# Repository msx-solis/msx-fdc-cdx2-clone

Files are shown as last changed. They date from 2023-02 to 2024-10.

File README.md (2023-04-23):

# msx-fdc-cdx2-clone
MSX compatible I/O Port Based Floppy Disk Controller interface.

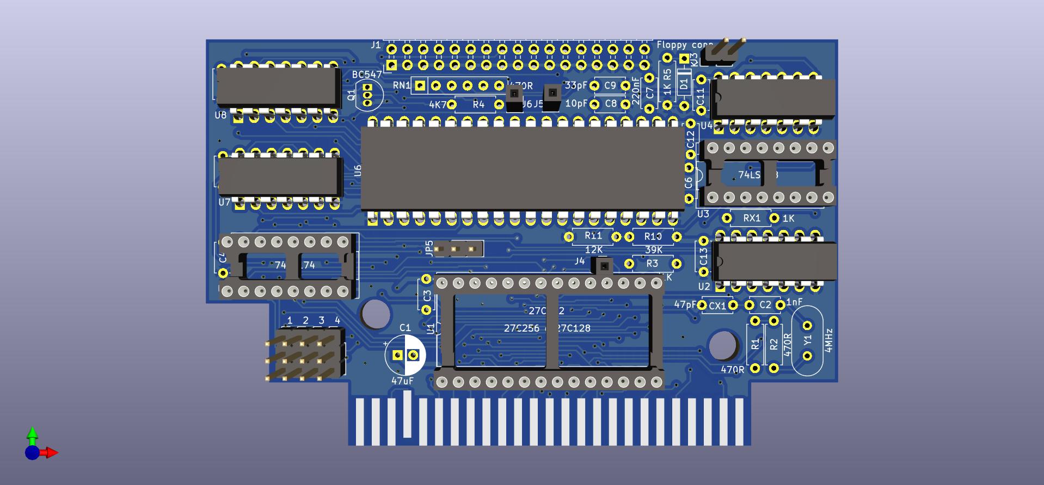
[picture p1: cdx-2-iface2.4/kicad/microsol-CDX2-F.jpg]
card


Please, continue reading at the following link for building instructions:

https://github.com/msx-solis/msx-fdc-cdx2-clone/blob/main/cdx-2-iface2.4/doc/README.md

Special thanks to Paulo Maluf, XaviRompe, Andortizg and konkotgit.

Similar project and additional info at:

https://github.com/konkotgit/fdd-cdx2

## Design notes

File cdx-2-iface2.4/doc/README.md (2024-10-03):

# Step by step debugging instructions
## Port Based Floppy Disk Drive controller for MSX computer

Recreated Microsol Tecnologia CDX-2 FDD interface with busdir signal upgrade.

### ROMs tested with this interface:

* CDX-2 (Microsol Tecnologia)
* Angeisa (Angeisa Eletronica LTDA)
* FAST!DiskROM

### ROMs that should work with this interface:

* DDX 1.0 (Digital Design)
* DMX 1.2 (Conector Informatica LTDA.)
* LIFTROM (Liftrom Informatica)
* MANUT (AMT Mamute)
* TPX 1.02 (TPX - Perifericos)

### ROM vs free BASIC memory

| ROM | Free BASIC Memory |
| --- |:---:|
| Angeisa (Angeisa Eletronica LTDA)  | 23430  |
| CDX-2 (Microsol Tecnologia)  | 23430  |
| DDX 1.0 (Digital Design)  | 20304  |
| DMX 1.2 (Conector Informatica LTDA.) | 20304  |
| LIFTROM (Liftrom Informatica)  | 20304  |
| MANUT (AMT Mamute)  | 23430  |
| TPX 1.02 (TPX - Perifericos)  | 23430  |
| FAST!DiskROM  | 25471  |

Solder in all components and sockets, using round pin sockets you should have a low profile design.
The Jumpers JP1 to JP4 should link 1-2 for standard MSX connection and 2-3 for to use a standard PC ribbon cable, but drive b: may not work in this case (test not done yet). JP5 selects the ROM software between two options.

Then follow the next testing steps.

First insert the 74LS00 and verify you have 4Mhz measuring here (you need a frequency-meter or an oscilloscope):
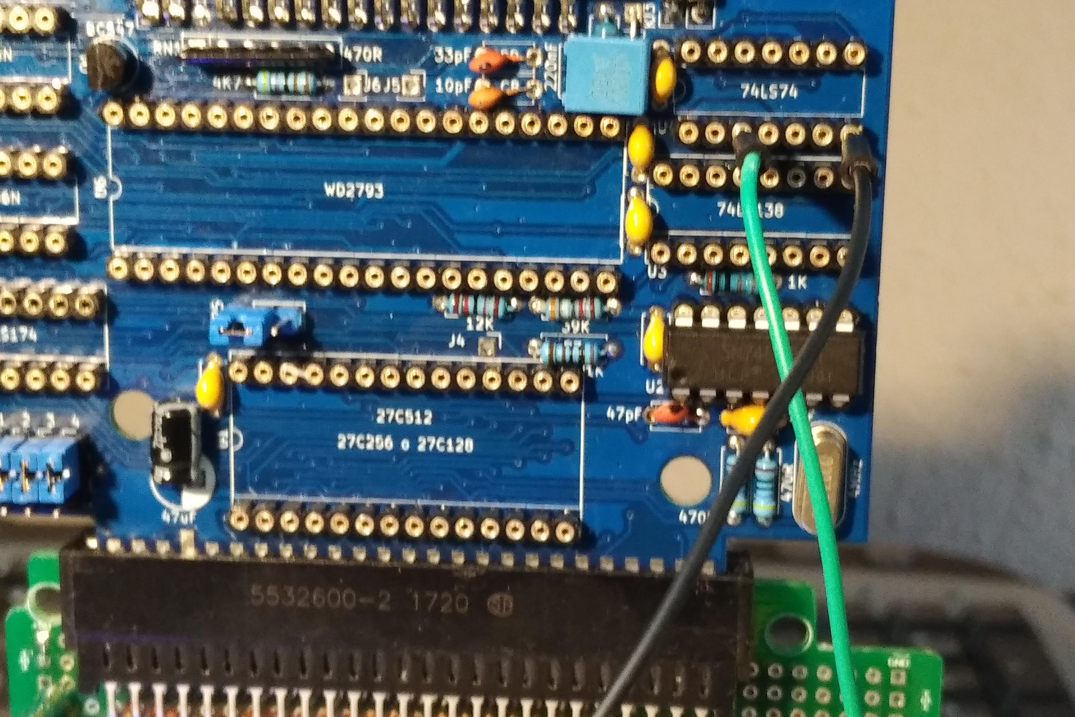
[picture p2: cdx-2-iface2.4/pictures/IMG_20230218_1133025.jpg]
4Mhz

Same way you can insert the 74LS74 IC and test you have 1Mhz here:
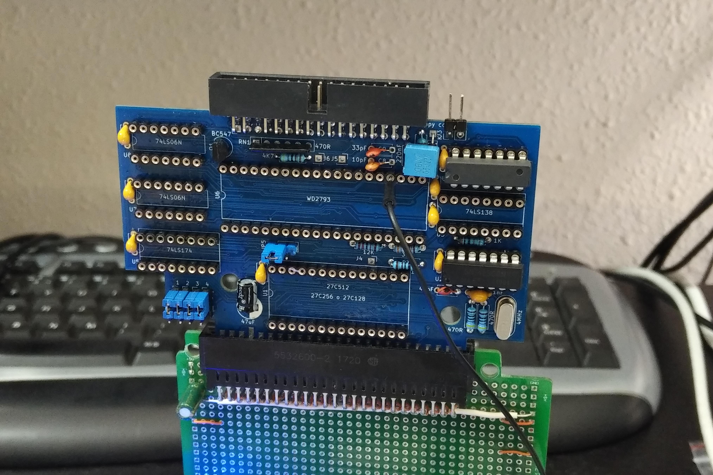
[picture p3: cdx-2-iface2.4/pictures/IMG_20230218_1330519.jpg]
1Mhz

Then test the reading select circuit is working properly doing the test shown in the following picture (and testing the result with a logic probe or a voltmeter):
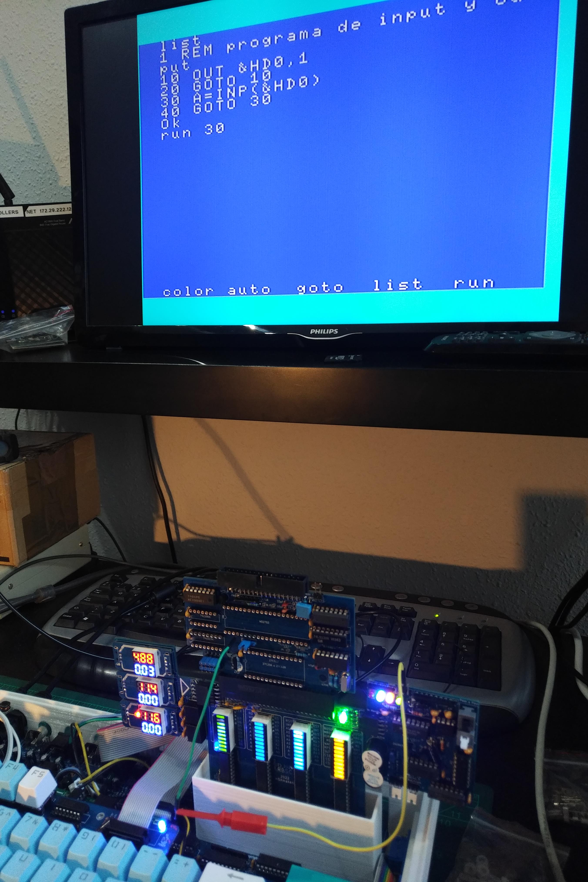
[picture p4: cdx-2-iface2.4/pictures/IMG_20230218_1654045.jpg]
read

You can use the same program (push ctrl-stop and RUN) for test writing port select circuit too (with the probe pin inserted at pin 2).
Click at the below picture to see a video showing it:
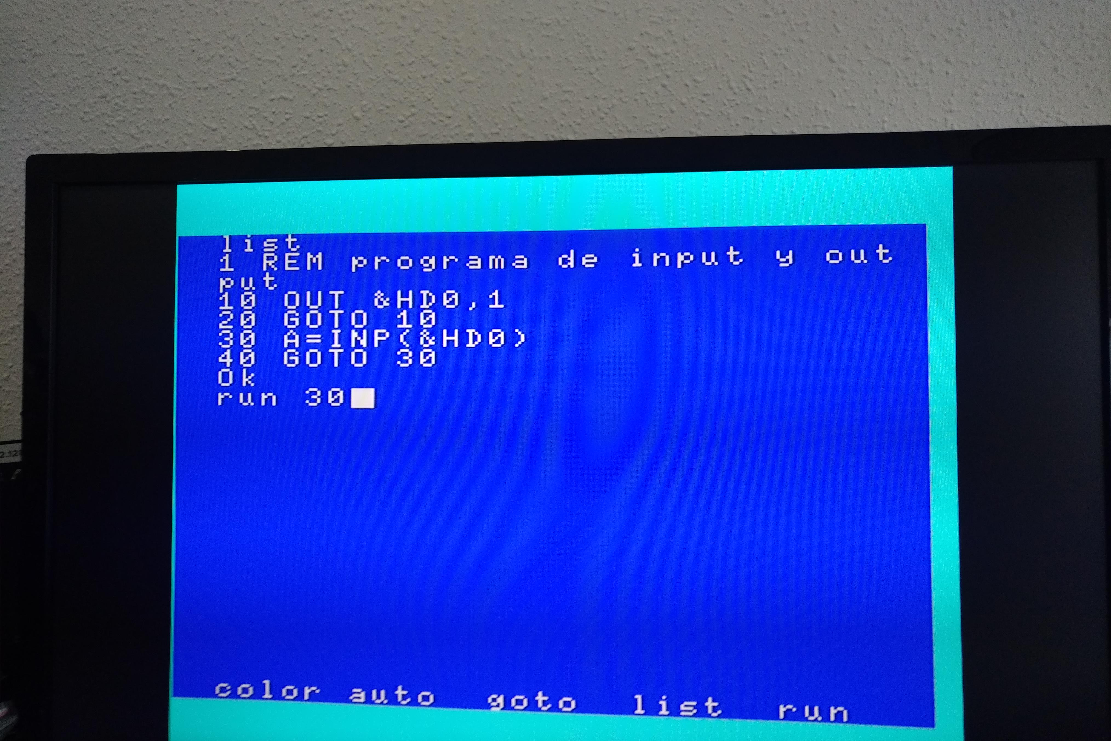
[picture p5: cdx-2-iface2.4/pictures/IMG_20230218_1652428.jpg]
YouTube link (https://youtu.be/hXyXDxHcx18)

After that you can also probe the hex D4 port with the following procedure:
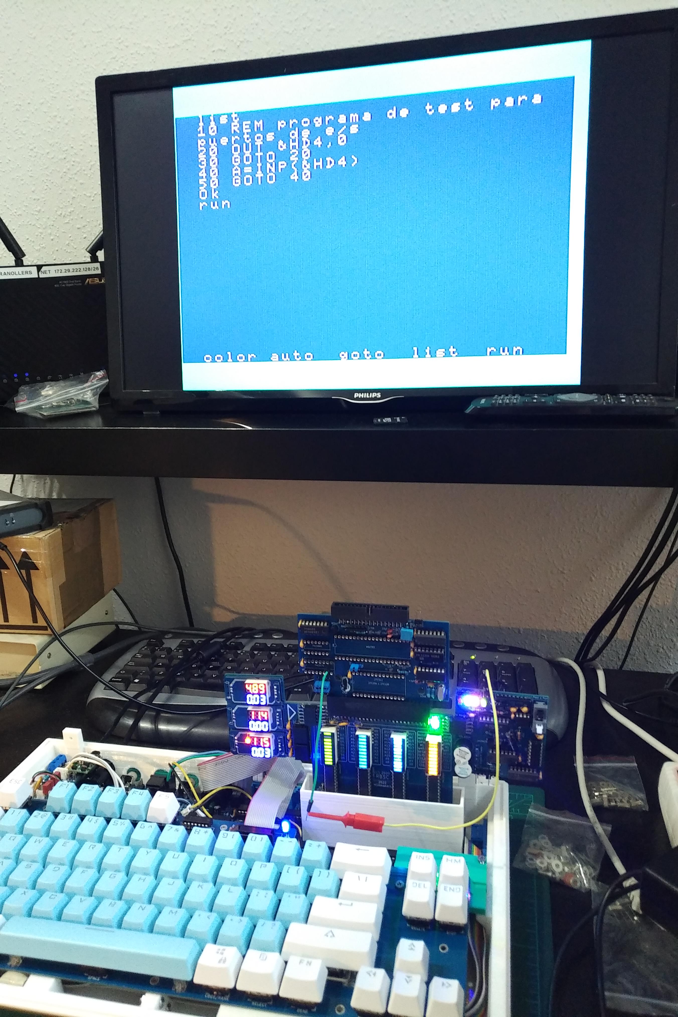
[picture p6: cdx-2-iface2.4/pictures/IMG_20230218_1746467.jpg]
D4

Now you must configure the jumpers JP1 to JP4 for the right drive and the right wire:

* To use an old DS0 MSX drive, build a direct straight ribbon cable and choose 1-2 at four jumpers. Direct straight drive connected will be A: and switching wires 10-12 drive B: DS0 (MSX) can be connected.
* To use a common DS1 PC drive and a ribbon PC twisted cable (with 10 to 16 wires crossed) chose 2-3 at those jumpers (only drive A will work).
* PC drives can also be used with an MSX setup, with a 10 to 12 ribbon twisted wire. For this setup move jumpers JP1-JP4 to 1-2 and connect two PC drives: direct straight will be drive B: and drive connected after switching 10-12 will be drive A:.
* Some drives also lets you choose what DS setup they are by jumpers, then use a direct straight ribbon cable with up to 5 connectors (4 drives) and setup each drive from DS0 to DS3.

Now try the following output commands (to test DS0 ON, DS1 ON, motor ON...) and test on the related pins. to know what should be the affected pin you must follow the schematic...
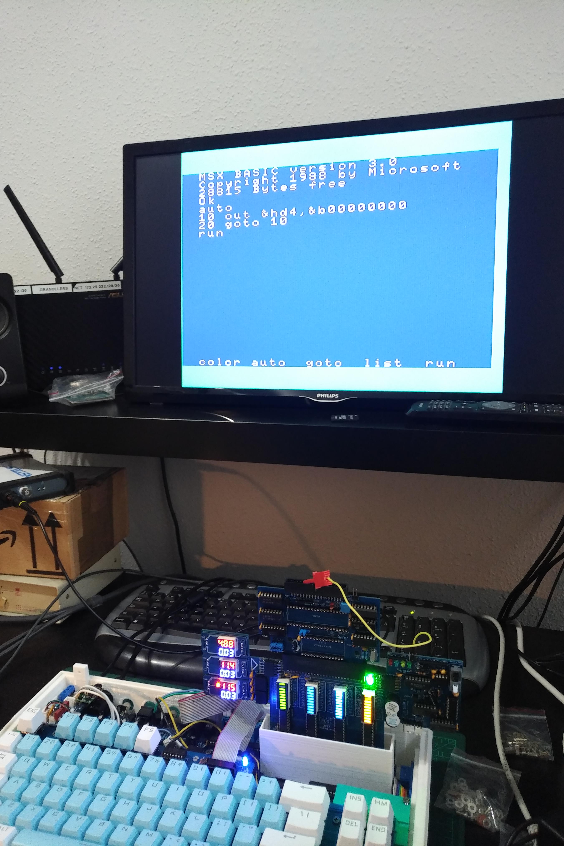
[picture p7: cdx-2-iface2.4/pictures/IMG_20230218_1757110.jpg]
binary1

...or you can connect now the floppy drive and test it. &b00100001 should on the A drive led, there's also bits for motor, etc:
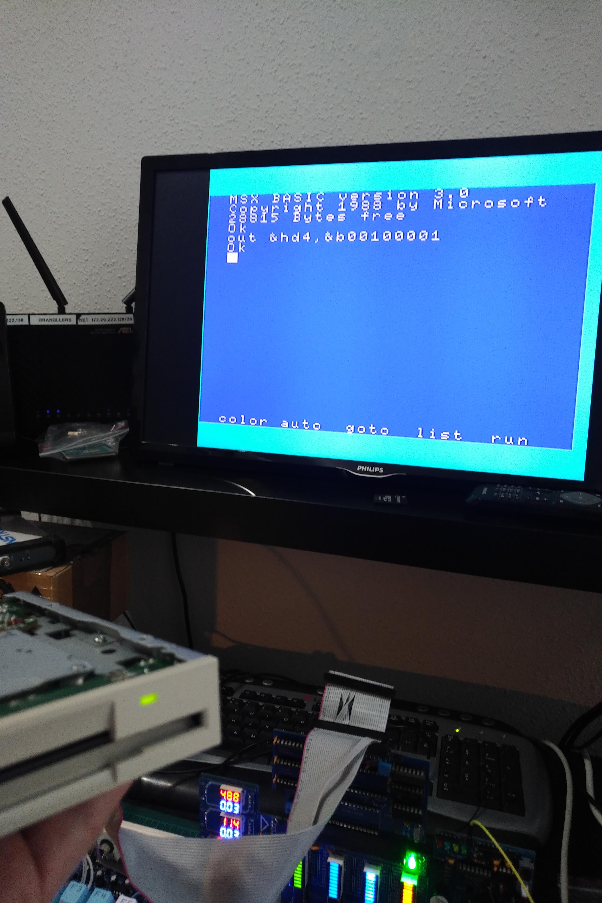
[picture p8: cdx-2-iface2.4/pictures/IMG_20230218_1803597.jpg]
binary2
 
Then, insert all pending IC and configure the JP5 to select your favorite ROM driver and try with a disk drive.
Angesia ROM would be the better software to use during the test process and FAST!DiskROM could be better option to improve the disk performance.

Floppy disk support must be formatted at the right format, MSX system does not support High density disks.
This means 3.5 HD disks must be formated after bloking the HD hole, using 720k/360k format (DSDD 80/40 tracks), and 5.25" disks must be also setup for 360k.
You can use a tool from a PC to dump MSX disks, is called Disk Manager: http://www.lexlechz.at/en/software/DiskMgr.html
Then you can use the disk dumps fount at https://download.file-hunter.com/ and get access to lots of software/games.

There's also lots of information for troubleshooting this interface reading the TMS2793 datasheet.
https://github.com/msx-solis/msx-fdc-cdx2-clone/raw/main/cdx-2-iface2.4/doc/tms2793.pdf

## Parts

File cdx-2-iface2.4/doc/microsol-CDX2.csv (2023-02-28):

Reference | Quantity | Value | Footprint | Datasheet
1 | 1 | DS0-sel | Connector_PinHeader_2.54mm:PinHeader_1x03_P2.54mm_Vertical
2 | 1 | DS1-sel | Connector_PinHeader_2.54mm:PinHeader_1x03_P2.54mm_Vertical
3 | 1 | DS2-sel | Connector_PinHeader_2.54mm:PinHeader_1x03_P2.54mm_Vertical
4 | 1 | MOTOR-sel | Connector_PinHeader_2.54mm:PinHeader_1x03_P2.54mm_Vertical
C1 | 1 | 47uF | Capacitor_THT:CP_Radial_D6.3mm_P2.50mm
C2 | 1 | 1nF | Capacitor_THT:C_Disc_D4.7mm_W2.5mm_P5.00mm
C3 C4 C5 C6 C10 C11 C12 C13 | 8 | 100nF | Capacitor_THT:C_Disc_D4.7mm_W2.5mm_P5.00mm
C7 | 1 | 220nF | Capacitor_THT:C_Disc_D4.7mm_W2.5mm_P5.00mm
C8 | 1 | 10pF | Capacitor_THT:C_Disc_D4.7mm_W2.5mm_P5.00mm
C9 | 1 | 33pF | Capacitor_THT:C_Disc_D4.7mm_W2.5mm_P5.00mm
CX1 | 1 | 47pF | Capacitor_THT:C_Disc_D4.7mm_W2.5mm_P5.00mm
D1 | 1 | 1N4148 | Diode_THT:D_DO-35_SOD27_P7.62mm_Horizontal | https://assets.nexperia.com/documents/data-sheet/1N4148_1N4448.pdf
J1 | 1 | Floppy conn | Connector_PinHeader_2.54mm:PinHeader_2x17_P2.54mm_Horizontal
J2 | 1 | MSX_SLOT_CON | MSXMakers:CARTRIDGE_#_MSX_XL
J3 | 1 | Test | Connector_PinHeader_2.54mm:PinHeader_1x02_P2.54mm_Vertical
J4 | 1 | TestPoint1 | Connector_PinSocket_2.54mm:PinSocket_1x01_P2.54mm_Vertical
J5 | 1 | TestPoint2 | Connector_PinSocket_2.54mm:PinSocket_1x01_P2.54mm_Vertical
J6 | 1 | TestPoint3 | Connector_PinSocket_2.54mm:PinSocket_1x01_P2.54mm_Vertical
JP5 | 1 | ROM_SW | Connector_PinHeader_2.54mm:PinHeader_1x03_P2.54mm_Vertical
Q1 | 1 | BC547 | Package_TO_SOT_THT:TO-92_Inline | https://www.onsemi.com/pub/Collateral/BC550-D.pdf
R1 R2 | 2 | 470R | Resistor_THT:R_Axial_DIN0207_L6.3mm_D2.5mm_P7.62mm_Horizontal
R10 | 1 | 39K | Resistor_THT:R_Axial_DIN0207_L6.3mm_D2.5mm_P7.62mm_Horizontal
R11 | 1 | 12K | Resistor_THT:R_Axial_DIN0207_L6.3mm_D2.5mm_P7.62mm_Horizontal
RX1 R3 R5 | 3 | 1K | Resistor_THT:R_Axial_DIN0207_L6.3mm_D2.5mm_P7.62mm_Horizontal
R4 | 1 | 4K7 | Resistor_THT:R_Axial_DIN0207_L6.3mm_D2.5mm_P7.62mm_Horizontal
RN1 | 1 | 470R | Resistor_THT:R_Array_SIP6 | http://www.vishay.com/docs/31509/csc.pdf
U1 | 1 | 27C256 o 27C128 | MSXmakers:DIP-28c_W15.24mm_Socket_LongPads | http://ww1.microchip.com/downloads/en/DeviceDoc/doc0014.pdf
U2 | 1 | 74LS00 | MSXmakers:DIP-14c_W7.62mm_LongPads | http://www.ti.com/lit/gpn/sn74ls00
U3 | 1 | 74LS138 | MSXmakers:DIP-16c_W7.62mm_Socket_LongPads | http://www.ti.com/lit/gpn/sn74LS138
U4 | 1 | 74LS74 | MSXmakers:DIP-14c_W7.62mm_LongPads | 74xx/74hc_hct74.pdf
U5 | 1 | 74LS174 | MSXmakers:DIP-16c_W7.62mm_Socket_LongPads | http://www.ti.com/lit/gpn/sn74LS174
U6 | 1 | WD2793 | MSXmakers:DIP-40c_W15.24mm_LongPads | http://pdf.datasheetcatalog.com/datasheets2/12/1229802_1.pdf
U7 U8 | 2 | 74LS06N | MSXmakers:DIP-14c_W7.62mm_LongPads | http://www.ti.com/lit/gpn/sn74LS06N
Y1 | 1 | 4MHz | Crystal:Crystal_HC49-U_Vertical

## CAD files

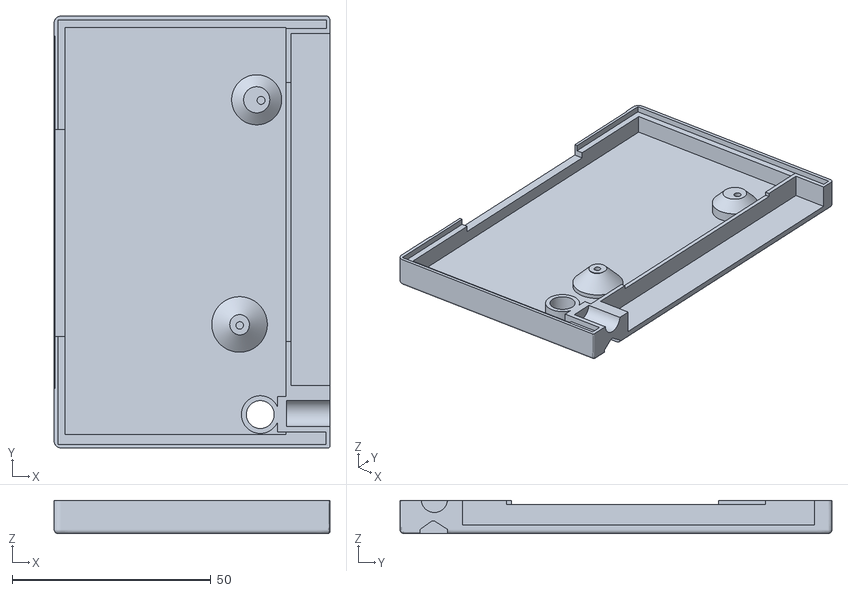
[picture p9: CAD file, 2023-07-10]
cartridge-case/cdx-2-2.4-case_botton.stl
69.3 x 108.6 x 8.30

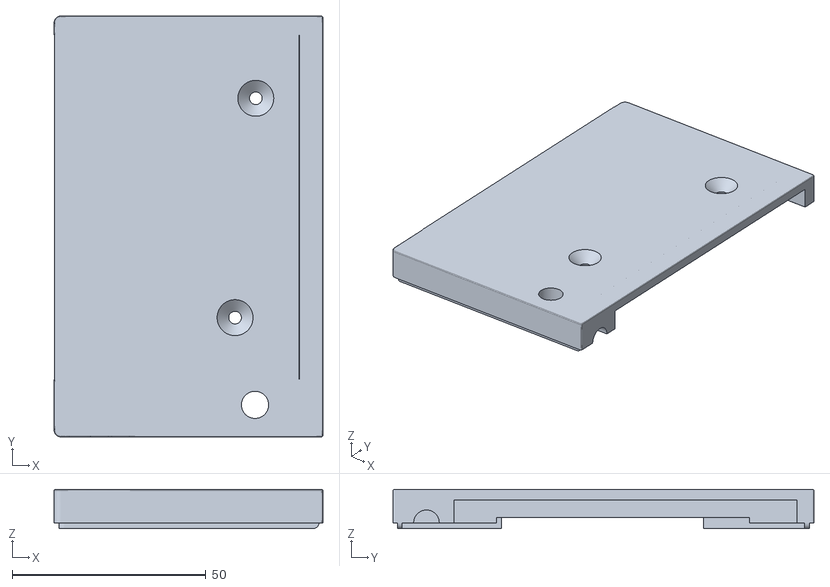
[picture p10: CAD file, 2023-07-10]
cartridge-case/cdx-2-2.4-case_top.stl
69.3 x 108.6 x 10.1

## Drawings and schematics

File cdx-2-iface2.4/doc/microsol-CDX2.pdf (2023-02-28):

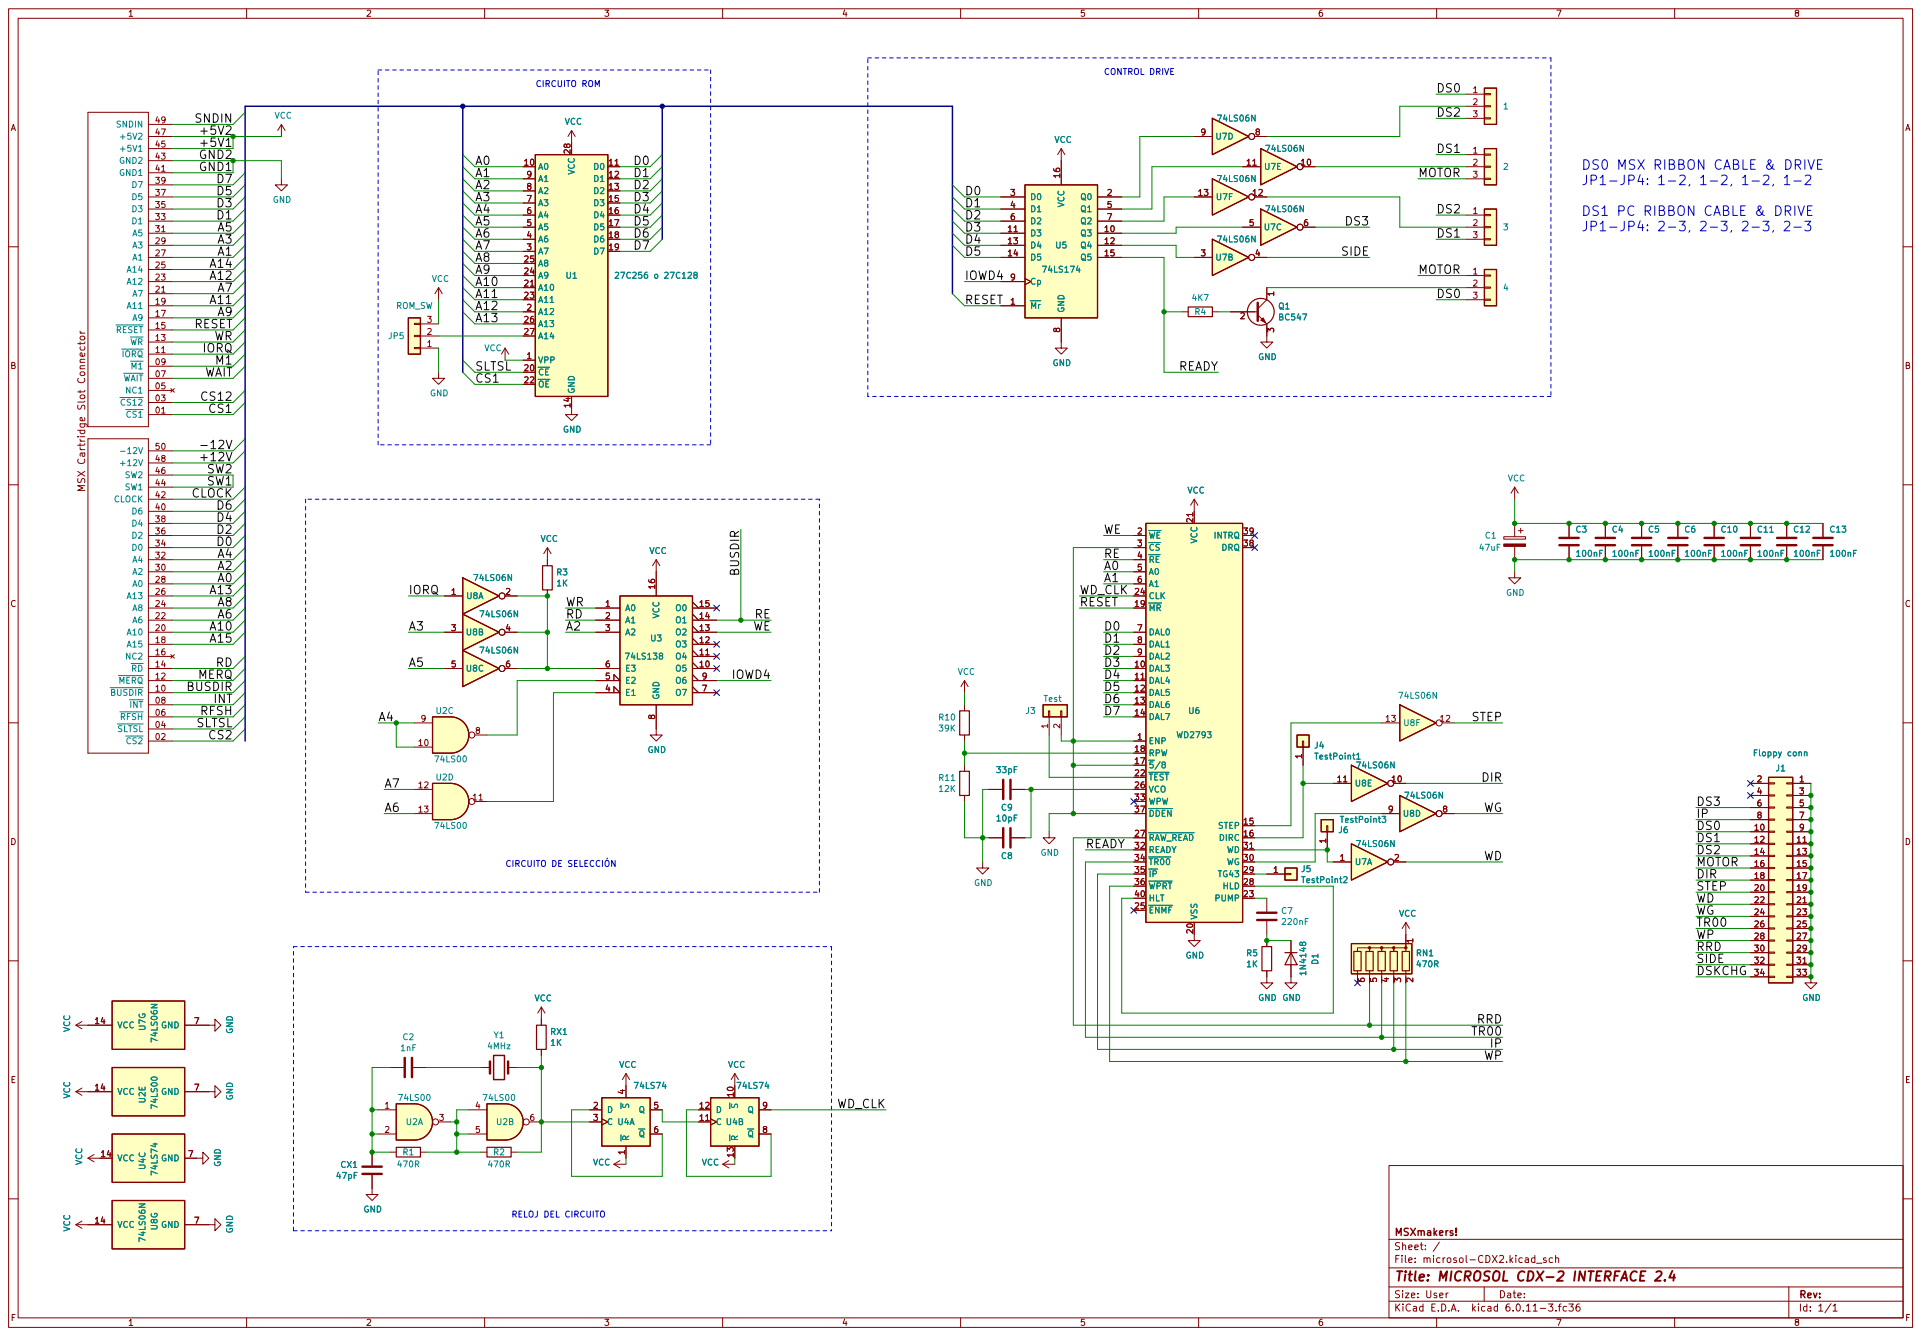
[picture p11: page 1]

CONTROL DRIVE

DS1 PC RIBBON CABLE & DRIVE

RESET

VCC MSX Cartridge Slot Connector

File: microsol-CDX2.kicad_sch Sheet: / MSXmakers!

Id: 1/1 Title: MICROSOL CDX-2 INTERFACE 2.4

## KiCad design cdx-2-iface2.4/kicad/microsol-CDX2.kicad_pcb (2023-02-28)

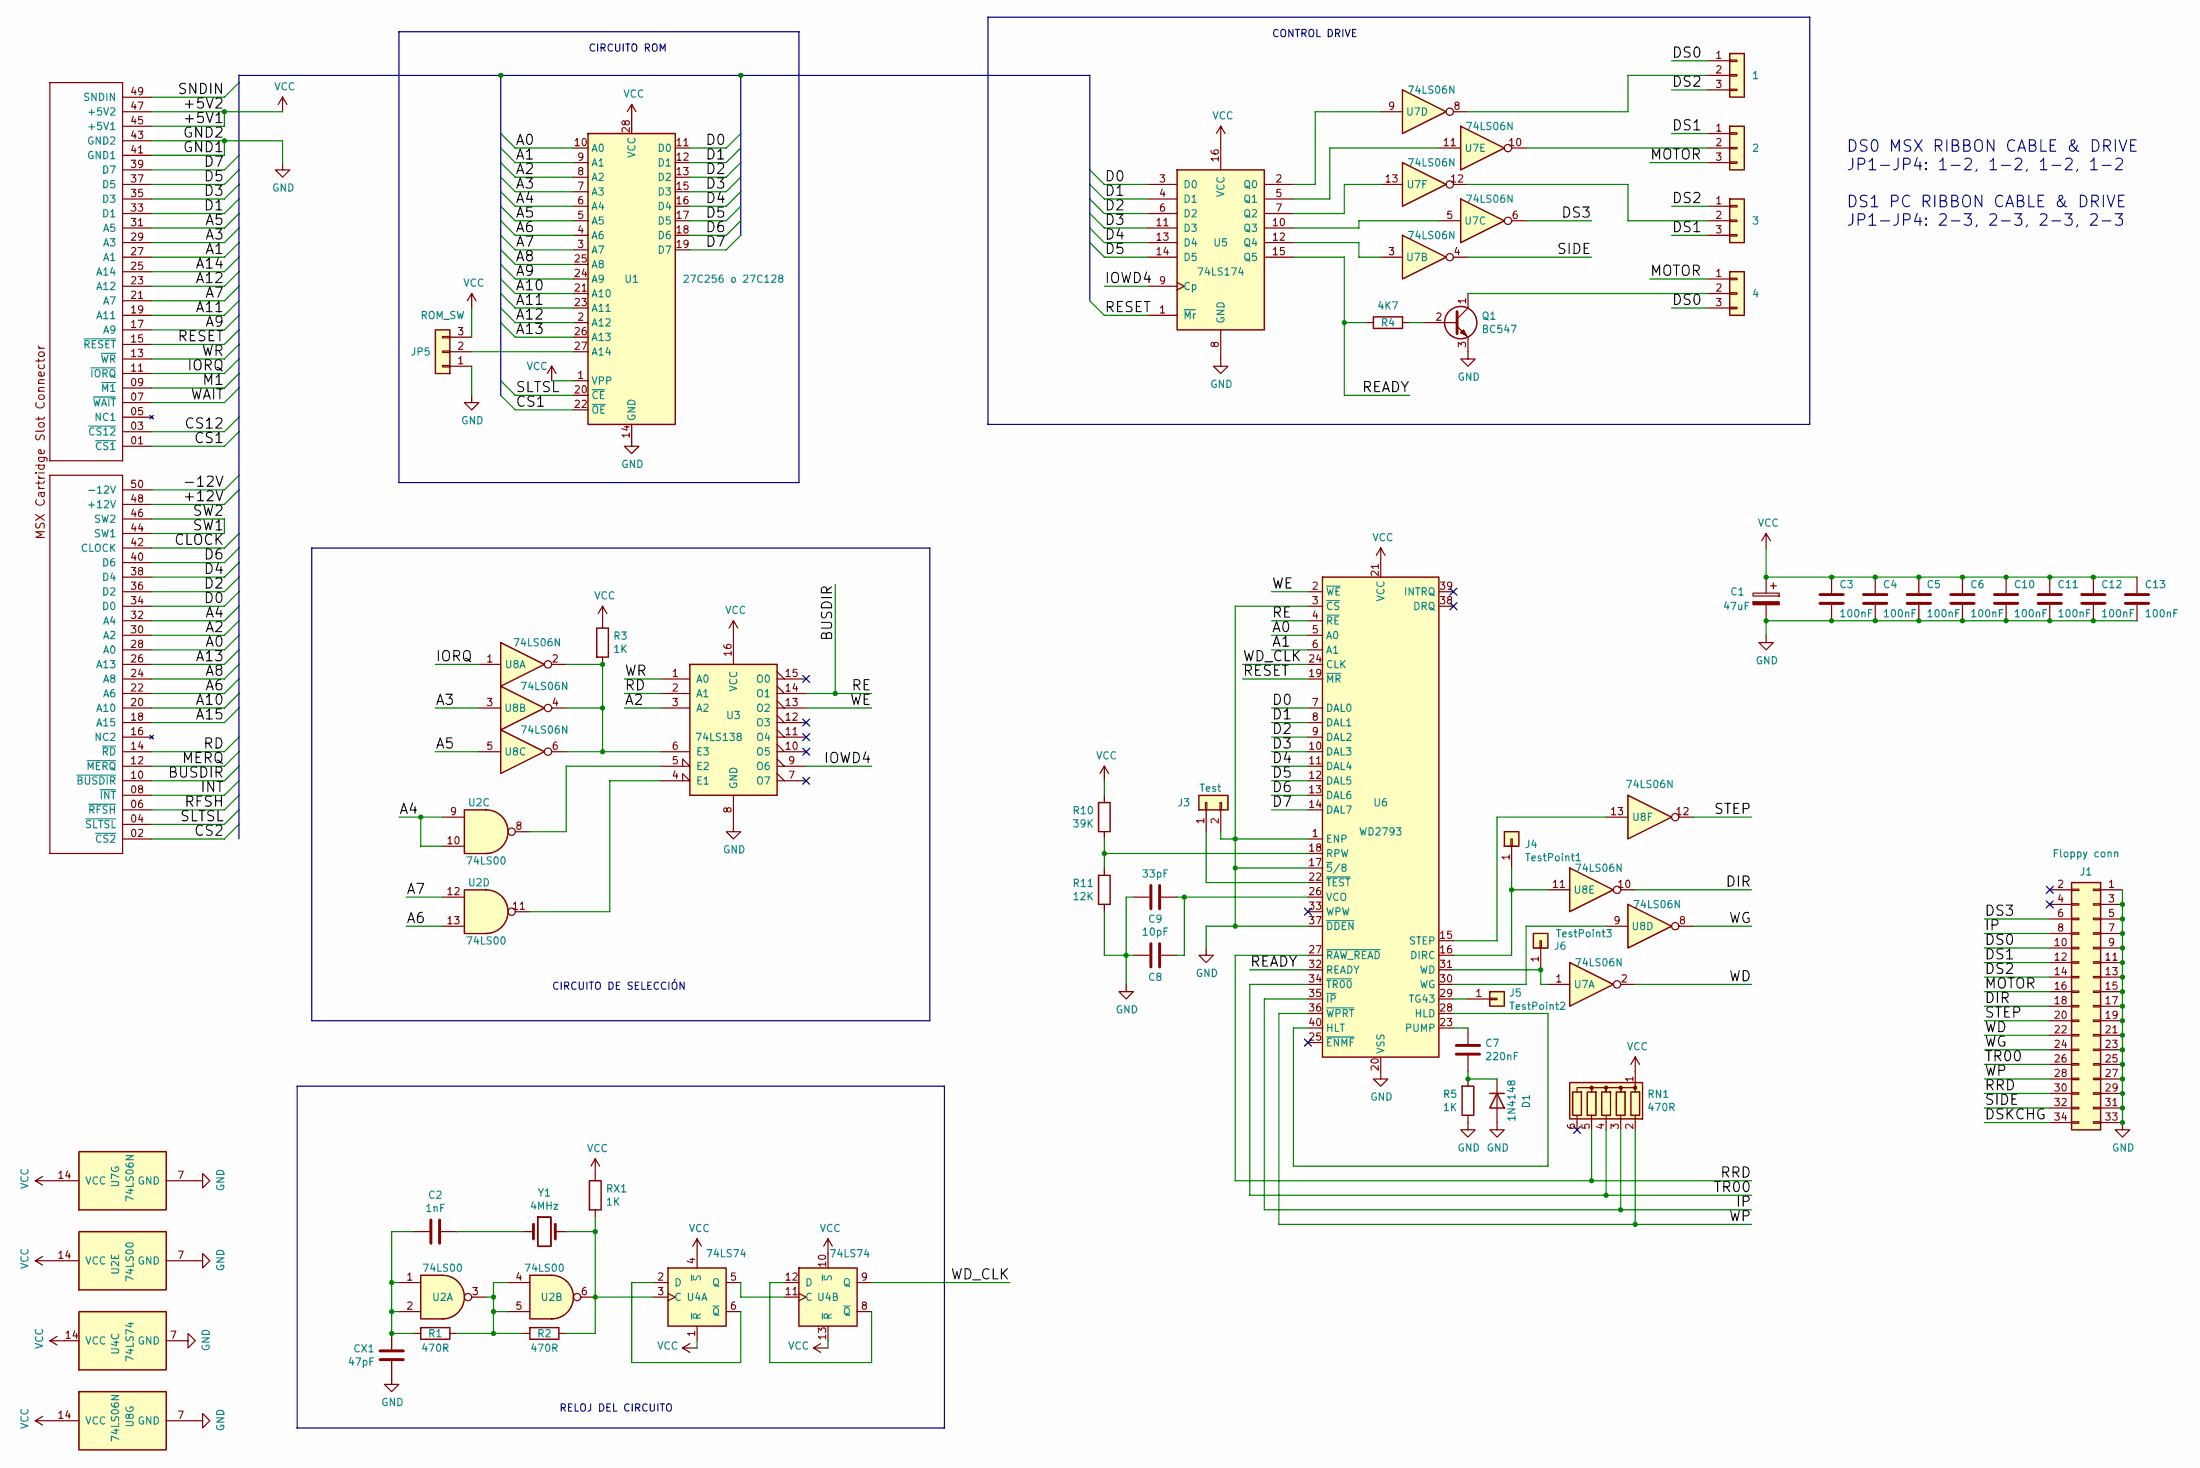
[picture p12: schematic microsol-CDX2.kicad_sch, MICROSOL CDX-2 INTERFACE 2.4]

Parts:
1: DS0-sel; PinHeader_1x03_P2.54mm_Vertical
2: DS1-sel; PinHeader_1x03_P2.54mm_Vertical
3: DS2-sel; PinHeader_1x03_P2.54mm_Vertical
4: MOTOR-sel; PinHeader_1x03_P2.54mm_Vertical
C1: 47uF; CP_Radial_D6.3mm_P2.50mm
C2: 1nF; C_Disc_D4.7mm_W2.5mm_P5.00mm
C3, C4, C5, C6, C10, C11, C12, C13: 100nF; C_Disc_D4.7mm_W2.5mm_P5.00mm
C7: 220nF; C_Disc_D4.7mm_W2.5mm_P5.00mm
C8: 10pF; C_Disc_D4.7mm_W2.5mm_P5.00mm
C9: 33pF; C_Disc_D4.7mm_W2.5mm_P5.00mm
CX1: 47pF; C_Disc_D4.7mm_W2.5mm_P5.00mm
D1: 1N4148; D_DO-35_SOD27_P7.62mm_Horizontal
J1: Floppy conn; PinHeader_2x17_P2.54mm_Horizontal
J2: MSX_SLOT_CON; CARTRIDGE_#_MSX_XL
J3: Test; PinHeader_1x02_P2.54mm_Vertical
J4: TestPoint1; PinSocket_1x01_P2.54mm_Vertical
J5: TestPoint2; PinSocket_1x01_P2.54mm_Vertical
J6: TestPoint3; PinSocket_1x01_P2.54mm_Vertical
JP5: ROM_SW; PinHeader_1x03_P2.54mm_Vertical
Q1: BC547; TO-92_Inline
R1, R2: 470R; R_Axial_DIN0207_L6.3mm_D2.5mm_P7.62mm_Horizontal
R3, R5: 1K; R_Axial_DIN0207_L6.3mm_D2.5mm_P7.62mm_Horizontal
R4: 4K7; R_Axial_DIN0207_L6.3mm_D2.5mm_P7.62mm_Horizontal
R10: 39K; R_Axial_DIN0207_L6.3mm_D2.5mm_P7.62mm_Horizontal
R11: 12K; R_Axial_DIN0207_L6.3mm_D2.5mm_P7.62mm_Horizontal
RN1: 470R; R_Array_SIP6
RX1: 1K; R_Axial_DIN0207_L6.3mm_D2.5mm_P7.62mm_Horizontal
U1: 27C256 o 27C128; DIP-28c_W15.24mm_Socket_LongPads
U2: 74LS00; DIP-14c_W7.62mm_LongPads
U3: 74LS138; DIP-16c_W7.62mm_Socket_LongPads
U4: 74LS74; DIP-14c_W7.62mm_LongPads
U5: 74LS174; DIP-16c_W7.62mm_Socket_LongPads
U6: WD2793; DIP-40c_W15.24mm_LongPads
U7, U8: 74LS06N; DIP-14c_W7.62mm_LongPads
Y1: 4MHz; Crystal_HC49-U_Vertical

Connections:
/+12V: J2.48 (+12V)
/-12V: J2.50 (-12V)
/A0: J2.28 (A0), U1.10 (A0), U6.5 (A0)
/A1: J2.27 (A1), U1.9 (A1), U6.6 (A1)
/A2: J2.30 (A2), U1.8 (A2), U3.3 (A2)
/A3: J2.29 (A3), U1.7 (A3), U8.3
/A4: J2.32 (A4), U1.6 (A4), U2.9, U2.10
/A5: J2.31 (A5), U1.5 (A5), U8.5
/A6: J2.22 (A6), U1.4 (A6), U2.13
/A7: J2.21 (A7), U1.3 (A7), U2.12
/A8: J2.24 (A8), U1.25 (A8)
/A9: J2.17 (A9), U1.24 (A9)
/A10: J2.20 (A10), U1.21 (A10)
/A11: J2.19 (A11), U1.23 (A11)
/A12: J2.23 (A12), U1.2 (A12)
/A13: J2.26 (A13), U1.26 (A13)
/A14: J2.25 (A14)
/A15: J2.18 (A15)
/BUSDIR: J2.10 (~BUSDIR), U3.14 (O1), U6.4 (~RE)
/CLOCK: J2.42 (CLOCK)
/CS1: J2.01 (~CS1), U1.22 (~OE)
/CS2: J2.02 (~CS2)
/CS12: J2.03 (~CS12)
/D0: J2.34 (D0), U1.11 (D0), U5.3 (D0), U6.7 (DAL0)
/D1: J2.33 (D1), U1.12 (D1), U5.4 (D1), U6.8 (DAL1)
/D2: J2.36 (D2), U1.13 (D2), U5.6 (D2), U6.9 (DAL2)
/D3: J2.35 (D3), U1.15 (D3), U5.11 (D3), U6.10 (DAL3)
/D4: J2.38 (D4), U1.16 (D4), U5.13 (D4), U6.11 (DAL4)
/D5: J2.37 (D5), U1.17 (D5), U5.14 (D5), U6.12 (DAL5)
/D6: J2.40 (D6), U1.18 (D6), U6.13 (DAL6)
/D7: J2.39 (D7), U1.19 (D7), U6.14 (DAL7)
/DIR: J1.18, U8.10
/DS0: 1.1, 4.3, J1.10
/DS1: 2.1, 3.3, J1.12
/DS2: 1.3, 3.1, J1.14
/DS3: J1.6, U7.6
/DSKCHG: J1.34
/INT: J2.08 (~INT)
/IORQ: J2.11 (~IORQ), U8.1
/IOWD4: U3.9 (O6), U5.9 (Cp)
/IP: J1.8, RN1.3 (R2), U6.35 (~IP)
/M1: J2.09 (~M1)
/MERQ: J2.12 (~MERQ)
/MOTOR: 2.3, 4.1, J1.16
/RD: J2.14 (~RD), U3.2 (A1)
/READY: R4.1, U5.15 (Q5), U6.32 (READY)
/RESET: J2.15 (~RESET), U5.1 (~Mr), U6.19 (~MR)
/RFSH: J2.06 (~RFSH)
/RRD: J1.30, RN1.5 (R4), U6.27 (~RAW_READ)
/SIDE: J1.32, U7.4
/SLTSL: J2.04 (~SLTSL), U1.20 (~CE)
/SNDIN: J2.49 (SNDIN)
/STEP: J1.20, U8.12
/SW1: J2.44 (SW1), J2.46 (SW2)
/TR00: J1.26, RN1.4 (R3), U6.34 (~TR00)
/WAIT: J2.07 (~WAIT)
/WD: J1.22, U7.2
/WD_CLK: U4.9 (Q), U6.24 (CLK)
/WE: U3.13 (O2), U6.2 (~WE)
/WG: J1.24, U8.8
/WP: J1.28, RN1.2 (R1), U6.36 (~WPRT)
/WR: J2.13 (~WR), U3.1 (A0)
GND: C1.2, C3.2, C4.2, C5.2, C6.2, C8.2, C9.1, C10.2, C11.2, C12.2, C13.2, CX1.1, D1.2 (A), J1.1, J1.3, J1.5, J1.7, J1.9, J1.11, J1.13, J1.15, J1.17, J1.19, J1.21, J1.23, J1.25, J1.27, J1.29, J1.31, J1.33, J2.41 (GND1), J2.43 (GND2), J3.2, JP5.1, Q1.3 (E), R5.1, R11.1, U1.14 (GND), U2.7 (GND), U3.8 (GND), U4.7 (GND), U5.8 (GND), U6.1 (ENP), U6.3 (~CS), U6.17 (~5/8), U6.20 (VSS), U6.37 (~DDEN), U7.7 (GND), U8.7 (GND)
unnamed: C2.1, Y1.1
unnamed: C2.2, CX1.2, R1.2, U2.1, U2.2
unnamed: C7.1, U6.23 (PUMP)
unnamed: C7.2, D1.1 (K), R5.2
unnamed: C8.1, C9.2, U6.26 (VCO)
unnamed: J3.1, U6.22 (~TEST)
unnamed: J4.1, U6.16 (DIRC), U8.11
unnamed: J5.1, U6.29 (TG43)
unnamed: J6.1, U6.31 (WD), U7.1
unnamed: 1.2, U7.8
unnamed: 2.2, U7.10
unnamed: 3.2, U7.12
unnamed: 4.2, Q1.1 (C)
unnamed: JP5.2, U1.27 (A14)
unnamed: Q1.2 (B), R4.2
unnamed: R1.1, R2.2, U2.3, U2.4, U2.5
unnamed: R2.1, RX1.2, U2.6, U4.3 (C), Y1.2
unnamed: R3.2, U3.6 (E3), U8.2, U8.4, U8.6
unnamed: R10.1, R11.2, U6.18 (RPW)
unnamed: U2.8, U3.5 (E2)
unnamed: U2.11, U3.4 (E1)
unnamed: U4.2 (D), U4.6 (~Q)
unnamed: U4.5 (Q), U4.11 (C)
unnamed: U4.8 (~Q), U4.12 (D)
unnamed: U5.2 (Q0), U7.9
unnamed: U5.5 (Q1), U7.11
unnamed: U5.7 (Q2), U7.13
unnamed: U5.10 (Q3), U7.5
unnamed: U5.12 (Q4), U7.3
unnamed: U6.15 (STEP), U8.13
unnamed: U6.28 (HLD), U6.40 (HLT)
unnamed: U6.30 (WG), U8.9
VCC: C1.1, C3.1, C4.1, C5.1, C6.1, C10.1, C11.1, C12.1, C13.1, J2.45 (+5V1), J2.47 (+5V2), JP5.3, R3.1, R10.2, RN1.1 (common), RX1.1, U1.1 (VPP), U1.28 (VCC), U2.14 (VCC), U3.16 (VCC), U4.1 (~R), U4.4 (~S), U4.10 (~S), U4.13 (~R), U4.14 (VCC), U5.16 (VCC), U6.21 (VCC), U7.14 (VCC), U8.14 (VCC)

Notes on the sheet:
CIRCUITO DE SELECCIÓN
RELOJ DEL CIRCUITO
CONTROL DRIVE
CIRCUITO ROM
DS0 MSX RIBBON CABLE & DRIVE JP1-JP4: 1-2, 1-2, 1-2, 1-2 DS1 PC RIBBON CABLE & DRIVE JP1-JP4: 2-3, 2-3, 2-3, 2-3

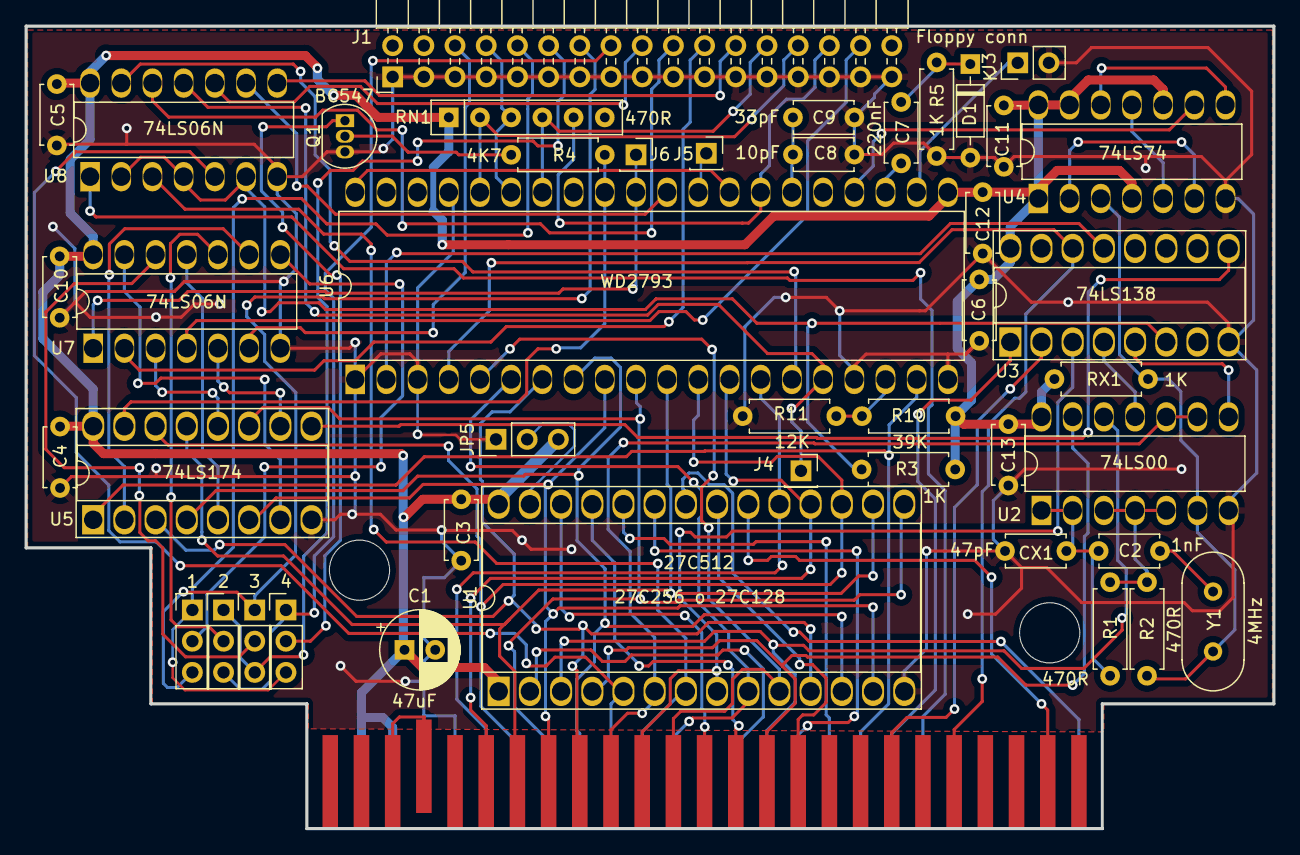
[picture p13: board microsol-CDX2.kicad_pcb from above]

Board: 2 copper layers, 101.6 x 65.3 mm, 45 parts (0 on the bottom side), 82 nets.
